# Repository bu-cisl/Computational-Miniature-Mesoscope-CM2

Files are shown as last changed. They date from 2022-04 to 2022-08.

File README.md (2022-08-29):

# Computational Miniature Mesoscope (CM<sup>2</sup>)
This is an open source repository of the Computational Miniature Mesoscope ([**CM<sup>2</sup>**](https://www.science.org/doi/full/10.1126/sciadv.abb7508)) project in the Computational Imaging Systems Lab ([**CISL**](https://sites.bu.edu/tianlab/)) at Boston University. We aim to develop next-generation “wearable” computational fluorescence microscope that achieves a centimeter-scale field-of-view (FOV) and micron-scale resolution with single-shot 3D imaging capability.
In this repository, we provide: 1) the hardware design of the CM<sup>2</sup> device including 3D printable CAD files of the LED, microlens array housing, and 3D printable freeform illuminators; 2) the Zemax models of the CM<sup>2</sup> system including the ZMX files, spectra data and coating profile; 3) the reconstruction algorithms: ADMM-based 3D deconvolution algorithm with calibrated 3D PSFs and sample measurements, and pre-trained CM<sup>2</sup>Net for fast, near-isotropic 3D reconstructions.

## Citation
If you find this project useful in your research, please consider citing our paper:

[**Yujia Xue, Ian G. Davison, David A. Boas, and Lei Tian. "Single-shot 3D wide-field fluorescence imaging with a Computational Miniature Mesoscope" Science advances 6, no. 43 (2020): eabb7508.**](https://www.science.org/doi/full/10.1126/sciadv.abb7508)

[**Yujia Xue, Qianwan Yang, Guorong Hu, Kehan Guo, and Lei Tian, "Deep-learning-augmented computational miniature mesoscope," Optica 9, 1009-1021 (2022).**](https://opg.optica.org/optica/fulltext.cfm?uri=optica-9-9-1009&id=497528)

## CM<sup>2</sup> V1
Fluorescence microscopes are indispensable to biology and neuroscience. The need for recording in freely behaving animals has further driven the development in miniaturized microscopes (miniscopes). However, conventional microscopes/miniscopes are inherently constrained by their limited space-bandwidth product, shallow depth of field (DOF), and inability to resolve three-dimensional (3D) distributed emitters. Here, we present a Computational Miniature Mesoscope (CM<sup>2</sup>) that overcomes these bottlenecks and enables single-shot 3D imaging across a 7-mm field of view and mm-scale DOF, achieving 7-μm lateral resolution and better than 200-μm axial resolution. The CM<sup>2</sup> features a compact lightweight design that integrates a microlens array for imaging and a light-emitting diode array for excitation. Its expanded imaging capability is enabled by computational imaging that augments the optics by algorithms. We experimentally validate the mesoscopic imaging capability on 3D fluorescent samples. We further quantify the effects of scattering and background fluorescence on phantom experiments.

<p align="center">
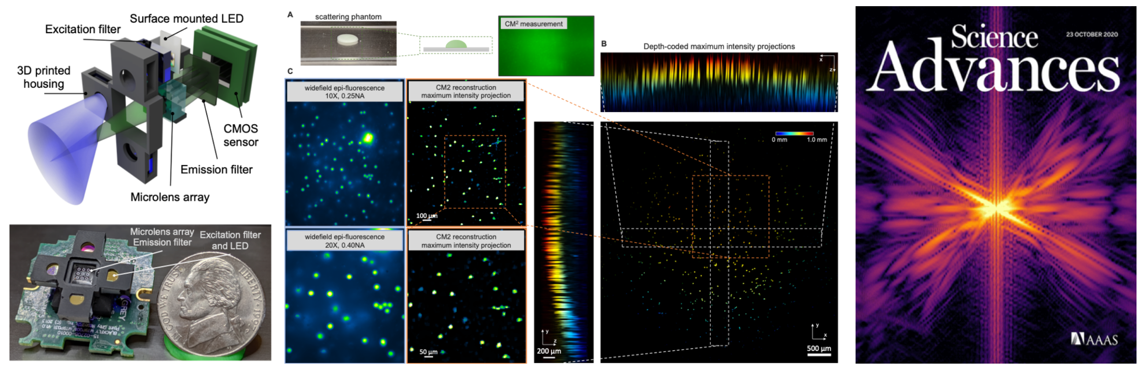
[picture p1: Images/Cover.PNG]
  
</p>

## CM<sup>2</sup> V2
Computational Miniature Mesoscope (CM<sup>2</sup>) is a recently developed computational imaging system that enables single-shot 3D imaging across a wide field-of-view (FOV) using a compact optical platform. In this work, we present CM<sup>2</sup> V2 - an advanced CM<sup>2</sup> system that integrates novel hardware improvements and a new deep learning reconstruction algorithm. The platform features a 3D-printed freeform LED collimator that achieves ~80% excitation efficiency - a ~3x improvement over our V1 design, and a hybrid emission filter design that improves the measurement contrast by >5x. The new computational pipeline includes an accurate and computationally efficient 3D linear shift-variant (LSV) forward model and a novel multi-module CM<sup>2</sup>Net deep learning model. As compared to the model-based deconvolution in our V1 system, CM<sup>2</sup>Net achieves ~8x better axial localization and ~1400x faster reconstruction speed. In addition, CM<sup>2</sup>Net consistently achieves high detection performance and superior axial localization across a wide FOV at a variety of conditions. Trained entirely on our 3D-LSV simulator generated training data set, CM<sup>2</sup>Net generalizes well to real experiments. We experimentally demonstrate that CM<sup>2</sup>Net achieves accurate 3D reconstruction of fluorescent emitters across a ~7-mm FOV and 800-μm depth, and provides ~6-μm lateral and ~25-μm axial resolution. We anticipate that this simple and low-cost computational miniature imaging system will be impactful to many large-scale 3D fluorescence imaging applications.

<p align="center">
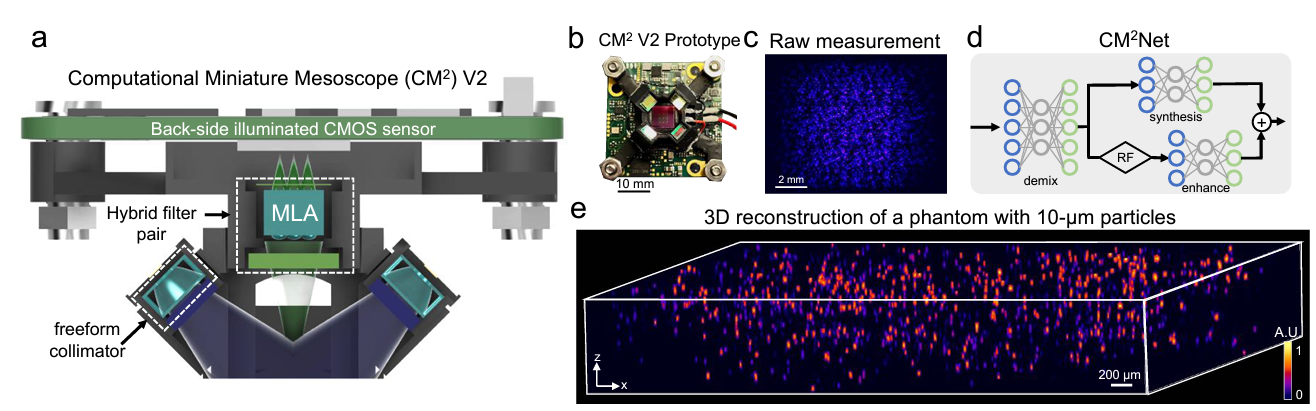
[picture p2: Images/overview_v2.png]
  
</p>

## How to use
### 1) Hardware design

The directory 'CAD_models' contains the CAD files of the CM<sup>2</sup>'s V1 and V2 systems, including the LED housing, microlens array housing, LED base plate and the freefrom collimator. All CAD models are 3D printable on lab table-top 3D printers. The subdirectory 'assembly' further provides an assembly of the CM<sup>2</sup> systems shown as below (note that the sensor is not to-scale).
<p align="center">
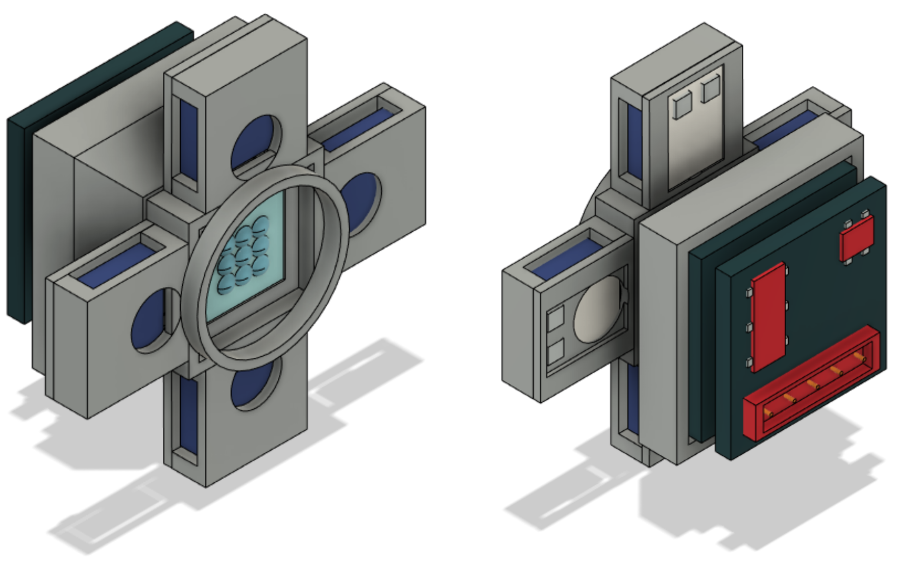
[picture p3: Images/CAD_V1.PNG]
  
</p>
<p align="center">
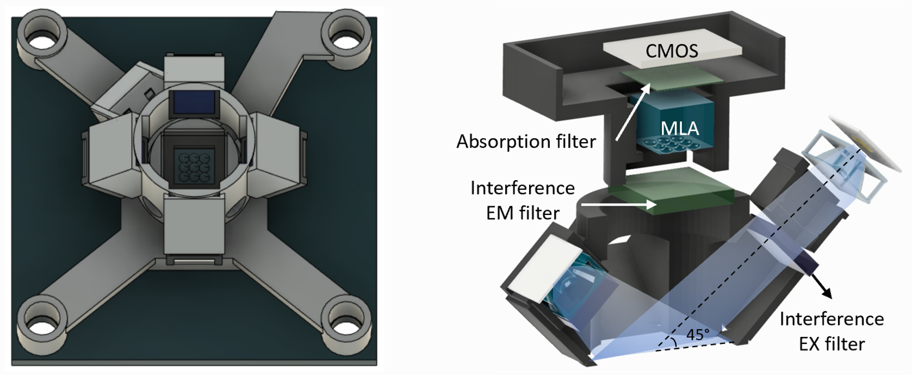
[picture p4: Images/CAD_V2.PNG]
  
</p>

The part list of all optical and electronic components used in the CM<sup>2</sup> prototypes can be found [**here**](https://docs.google.com/spreadsheets/d/1yO0x0pHvZYl-6WYT2bZiUERogTGQaifCt07Zwj_Rsxw/edit?usp=sharing).

### 2) Zemax model

To use the Zemax models, after cloning this repository, copy the coating file "cm2_coating_profiles_ver2.DAT" to the directory "Zemax\Coatings\", copy the spectra files "gfp_emission.spcd" and "led_spectrum_interp.spcd" to the directory "Zemax\Objects\Sources\Spectrum Files\", copy the CAD files (end with '.stl') to the directory "Zemax\Objects\CAD Files\", and then open "CM2_V1_opensource.zos" or "CM2_V2_opensource.zos" in Zemax to view the CM<sup>2</sup> design and ray tracing results. Pre-rendered ray tracing data can be downloaded [**here**](https://drive.google.com/drive/folders/10xuGhUDethVntPEySfjDurRVyuz1iKvr?usp=sharing).

#### CM<sup>2</sup> V1 Zemax model:
<p align="center">
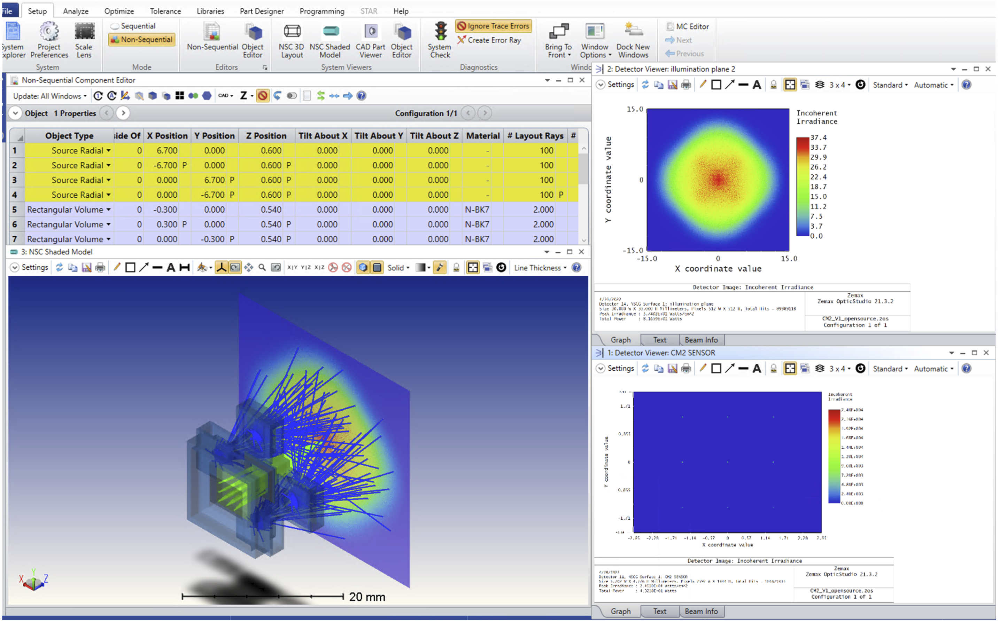
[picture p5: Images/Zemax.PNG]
  
</p>

#### CM<sup>2</sup> V2 Zemax model:
<p align="center">
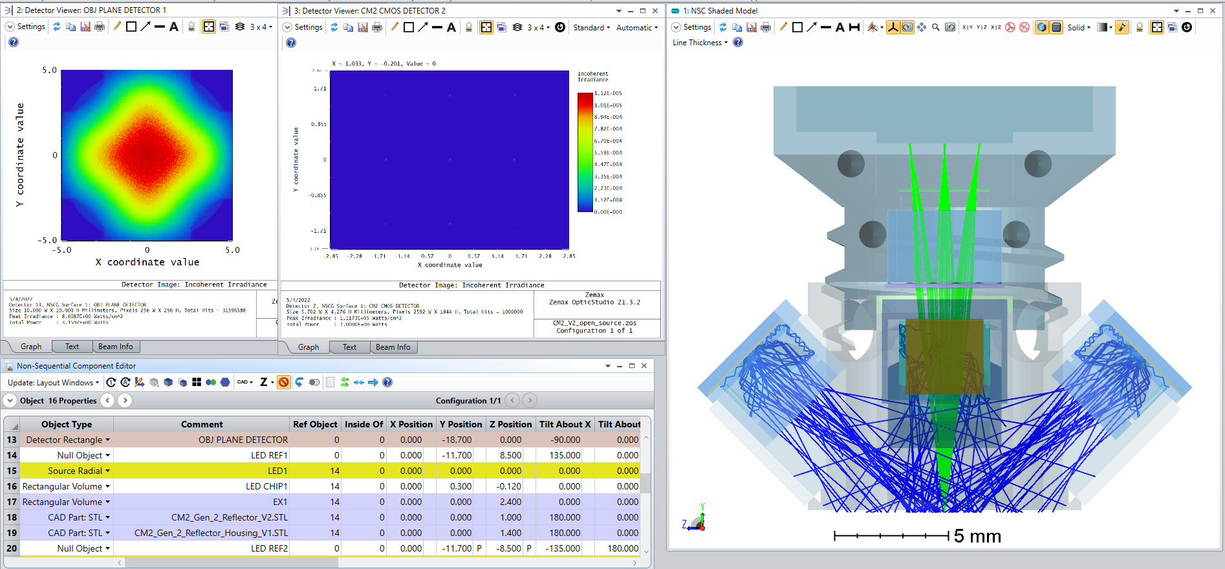
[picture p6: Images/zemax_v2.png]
  
</p>

### 3) Model-based 3D deconvolution
The script "cm2_related_code.m" in the "Algorithm" folder provides a demo of CM<sup>2</sup> 3D reconstruction pipeline on a simulated measurement using [down-sampled PSFs](https://drive.google.com/drive/folders/10xuGhUDethVntPEySfjDurRVyuz1iKvr?usp=sharing). A full-scale experimental measurement is also provided under the "Algorithm" direcory, which requires large system memory to run. The GIF file below shows the flying-through of a reconstructed 3D object (a fluorescent fiber sample) from an experimental measurement.

<p align="center">
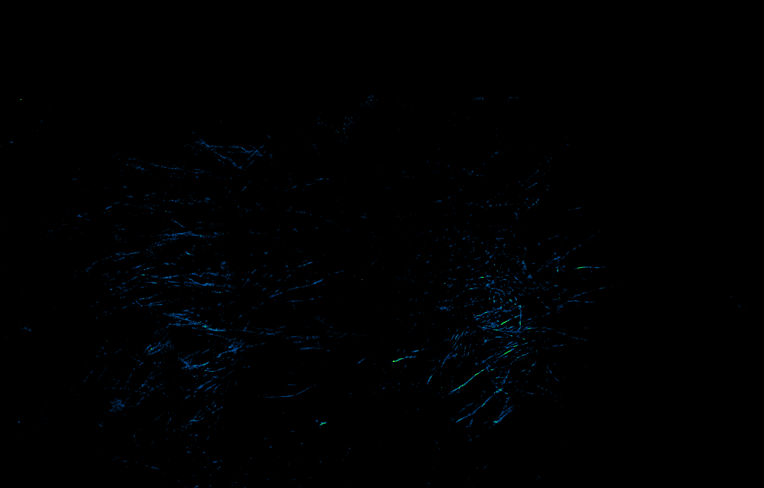
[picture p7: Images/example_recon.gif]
  
</p>

### 4）CM<sup>2</sup>Net: fast and near-isotropic 3D reconstruction
#### Install dependencies:
The CM<sup>2</sup>Net is implemented in Python 3.7 with TensorFlow 2.3.
#### Demo:
We provide an example of how to use the trained CM<sup>2</sup>net for fast and robust 3D reconstruction on CM<sup>2</sup> measurement. The script “cm2_models.py” and "pred_cm2net.py" in the "Algorithm/cm2net" folder provides the deep learning model and the inference code. The pretrained model, sample measurement and ground truth volume can be found in [cm2net data](https://drive.google.com/drive/folders/10xuGhUDethVntPEySfjDurRVyuz1iKvr?usp=sharing), which requires large system memory to run. The GIF file below shows the reconstructed 3D volume for the sample measurement.

<p align="center">
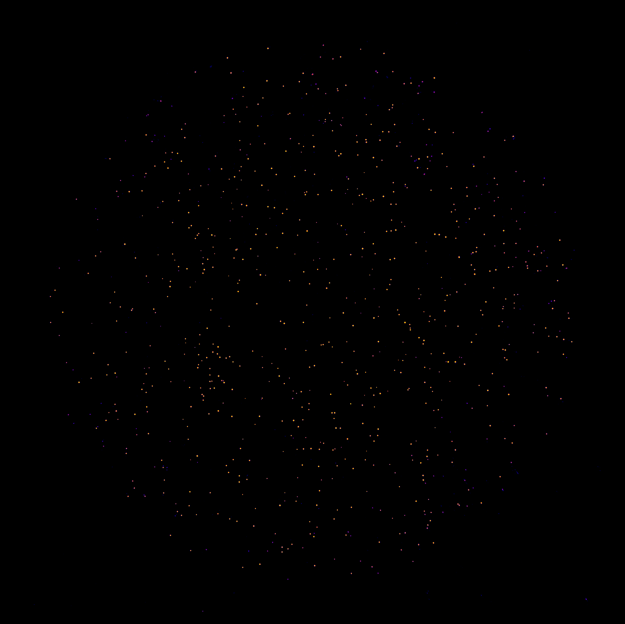
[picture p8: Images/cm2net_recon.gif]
  
</p>

## Contact
For further information, please feel free to contact us: Guorong Hu (grhu@bu.edu), Qianwan Yang (yaw@bu.edu), and Prof. Lei Tian (leitian@bu.edu).

## License
This project is licensed under the terms of the MIT license. see the [LICENSE](LICENSE) file for details

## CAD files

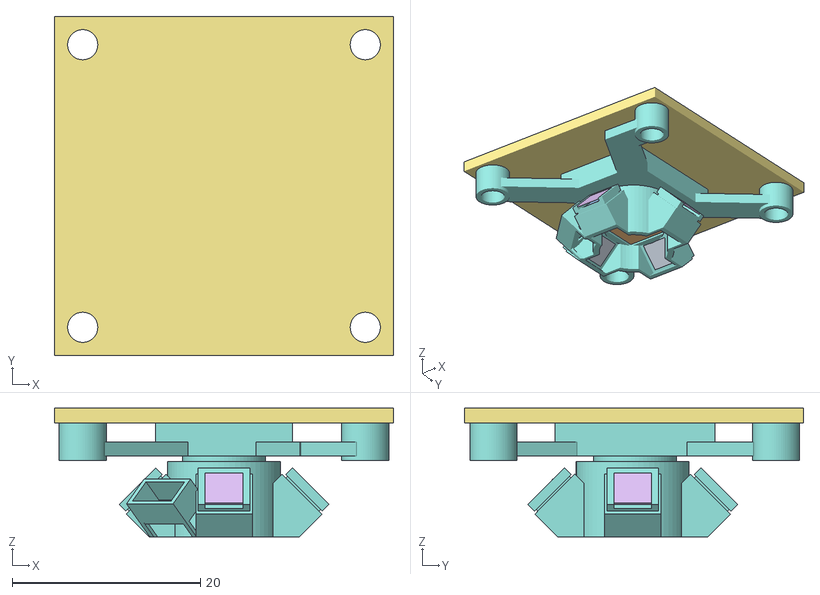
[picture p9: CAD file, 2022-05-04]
CAD_models/CM2_V2/assembly/CM2_V2_assembly_long_WD/CM2_V2_assembly_long_WD.obj
36.0 x 36.0 x 13.7

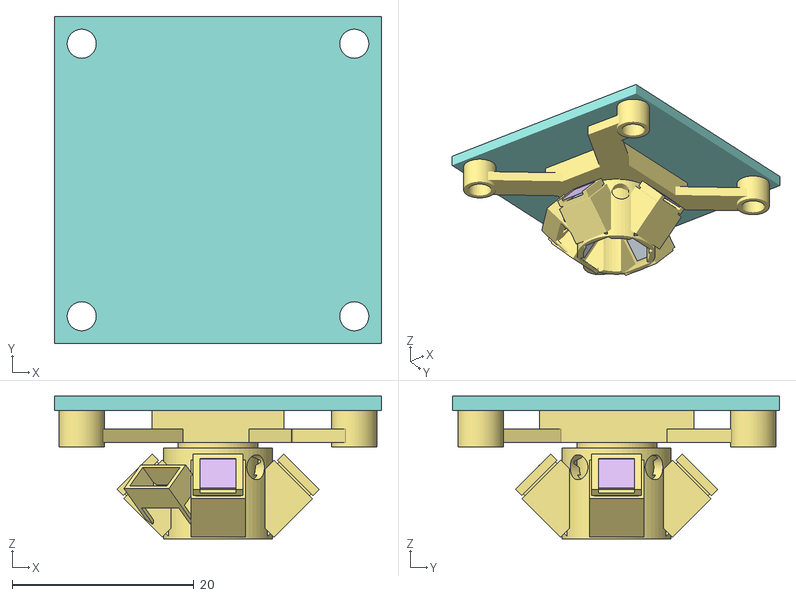
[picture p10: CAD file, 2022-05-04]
CAD_models/CM2_V2/assembly/CM2_V2_assembly_short_WD/CM2_V2_assembly_short_WD.obj
36.0 x 36.0 x 15.7

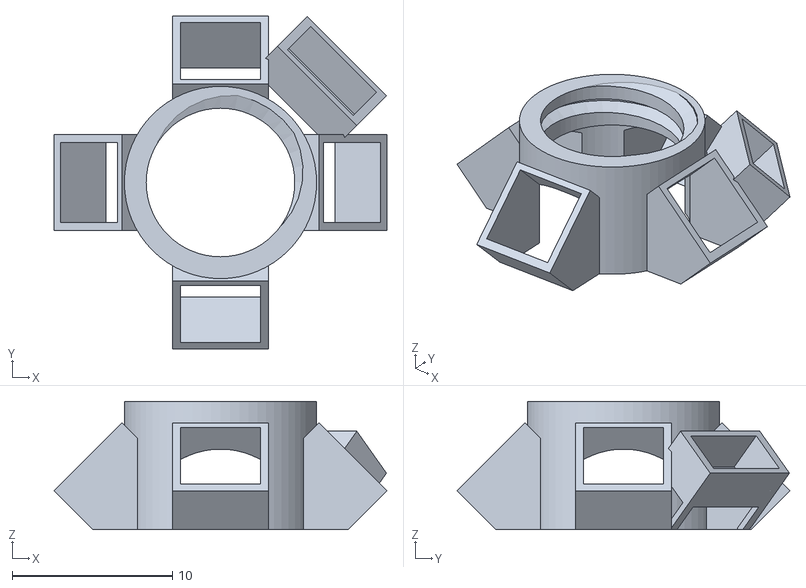
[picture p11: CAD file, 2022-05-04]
CAD_models/CM2_V2/CM2_V2_LED_array_housing_long_WD.stl
20.8 x 20.8 x 8.00

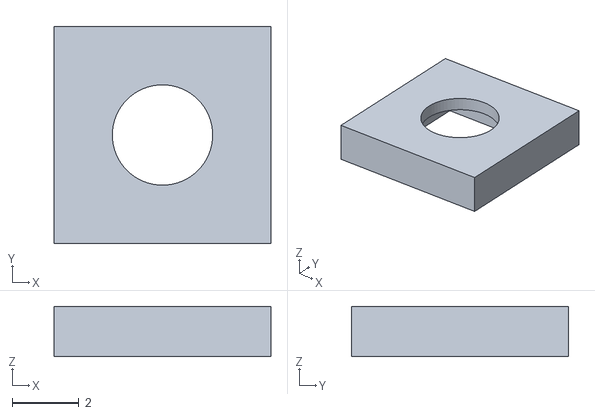
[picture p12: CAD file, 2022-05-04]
Zemax_models/CM2_V2/zemax_led_aperture.stl
6.50 x 6.50 x 1.50

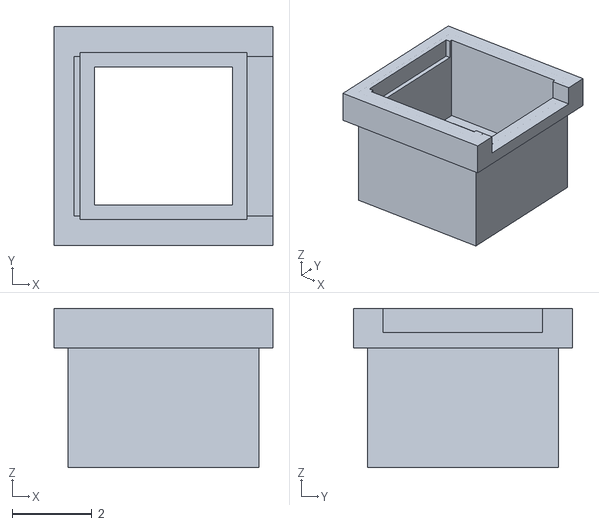
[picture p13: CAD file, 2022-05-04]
CAD_models/CM2_V2/CM2_V2_single_LED_housing.stl
5.50 x 5.50 x 4.00

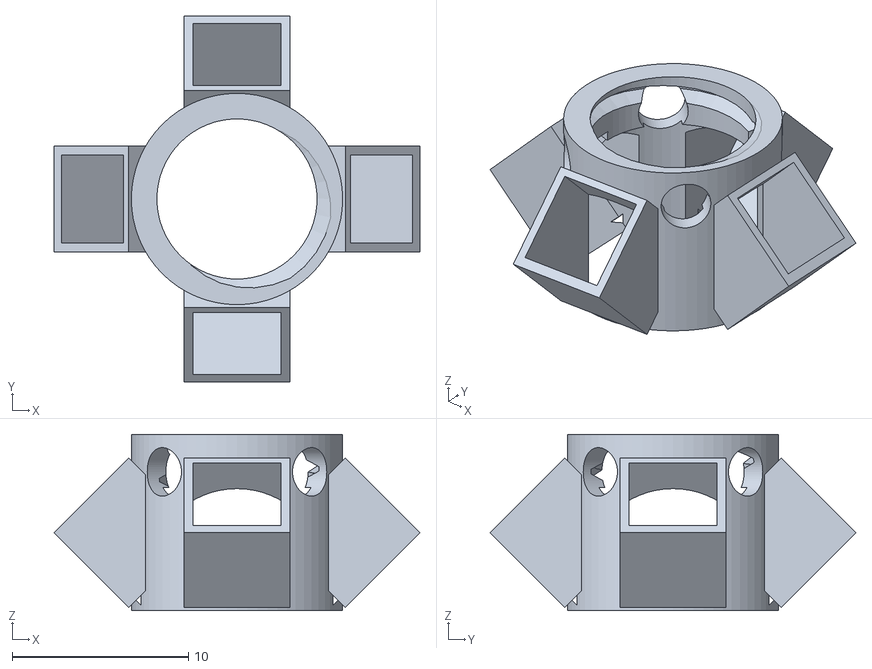
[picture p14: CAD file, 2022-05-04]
Zemax_models/CM2_V2/CM2_Gen_2_LED_Base_Threaded_V2.stl
20.8 x 20.8 x 10.0

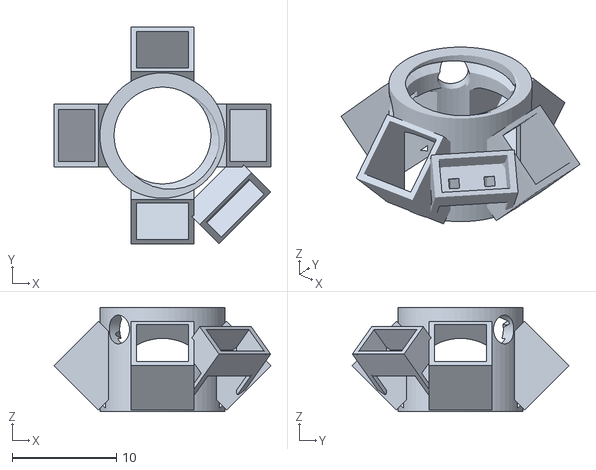
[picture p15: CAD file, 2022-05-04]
CAD_models/CM2_V2/CM2_V2_LED_array_housing_short_WD.stl.stl
20.8 x 20.8 x 10.0

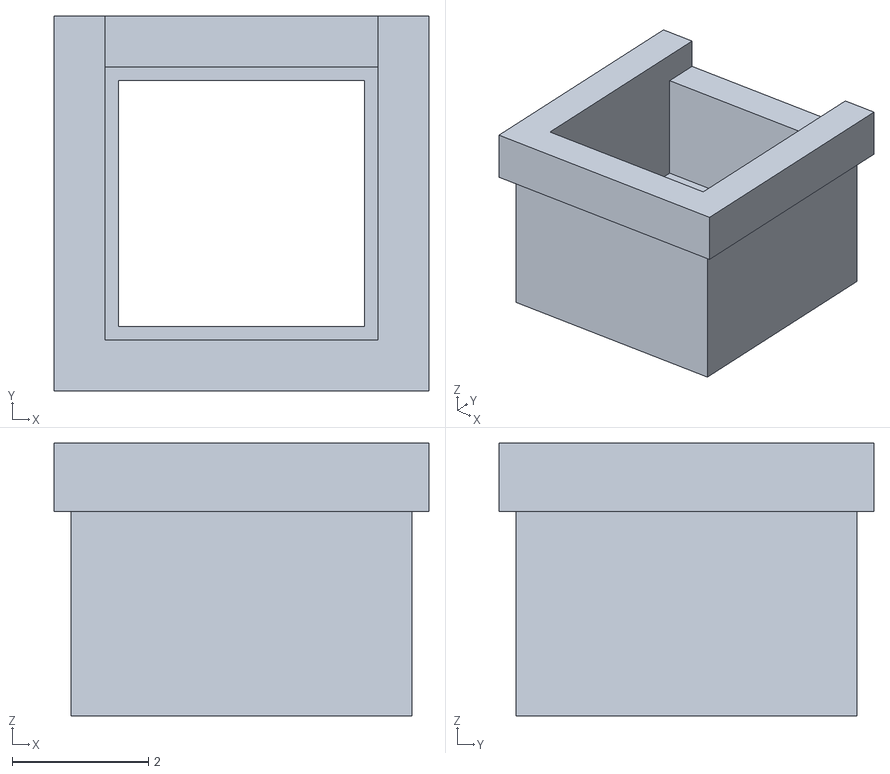
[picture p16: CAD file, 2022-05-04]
Zemax_models/CM2_V2/CM2_Gen_2_Reflector_Housing_V1.stl
5.50 x 5.50 x 4.00

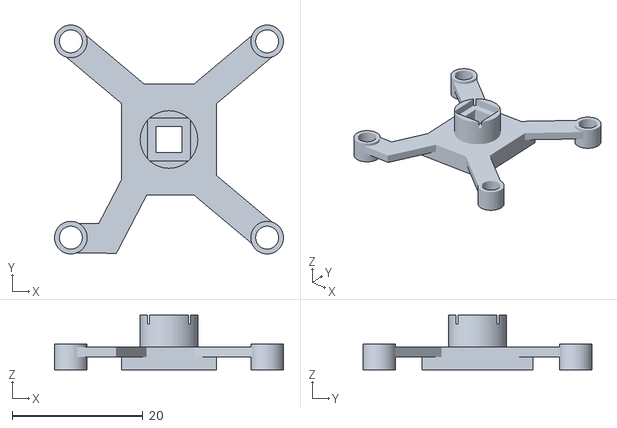
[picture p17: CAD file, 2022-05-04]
CAD_models/CM2_V2/CM2_V2_MLA_housing_IMX178.stl
35.0 x 35.0 x 8.40

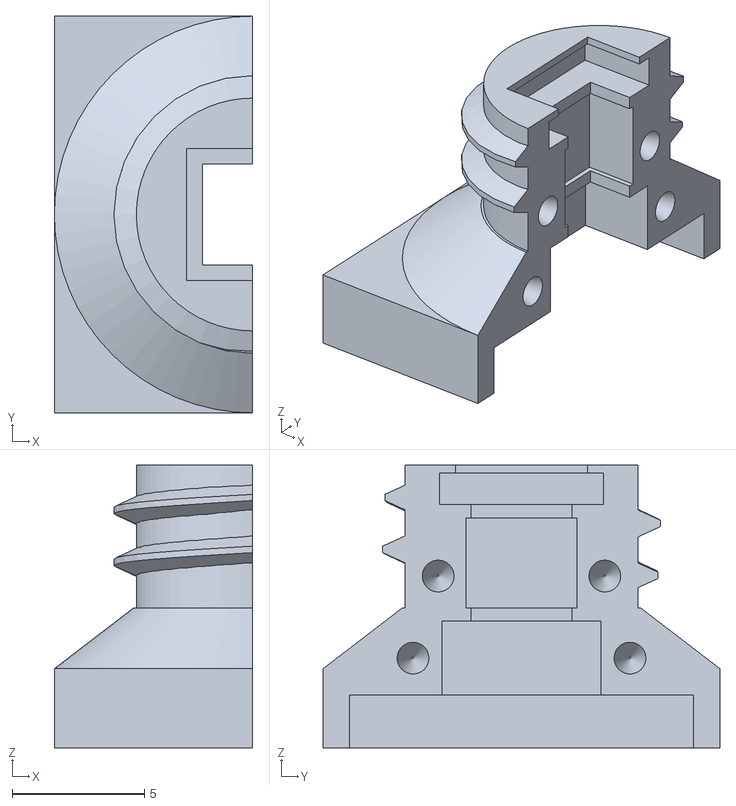
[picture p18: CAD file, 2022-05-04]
Zemax_models/CM2_V2/CM2_Gen_2_Top_Threaded_FEMALE_V2.stl
7.50 x 15.0 x 10.7

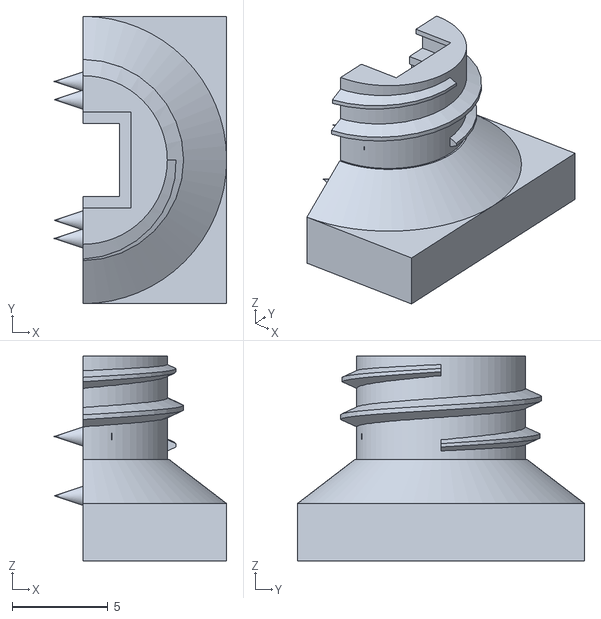
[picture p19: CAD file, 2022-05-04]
Zemax_models/CM2_V2/CM2_Gen_2_Top_Threaded_MALE_V2.stl
9.00 x 15.0 x 10.7

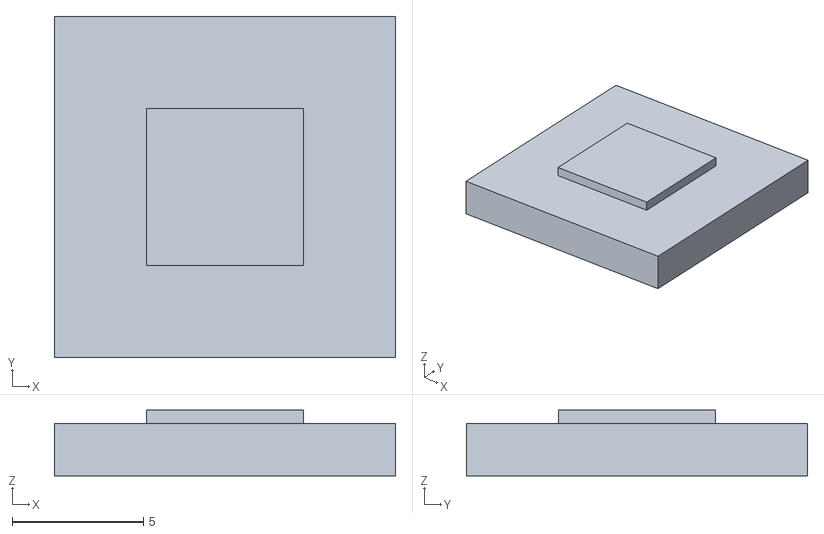
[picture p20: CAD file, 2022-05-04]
Zemax_models/CM2_V2/CM2_Gen_2_Mini_CMOS.stl
13.0 x 13.0 x 2.50

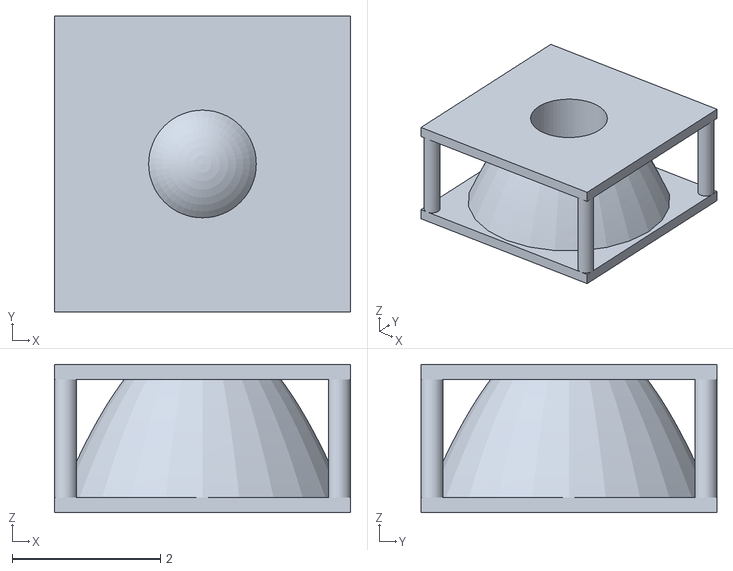
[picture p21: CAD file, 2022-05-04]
Zemax_models/CM2_V2/CM2_Gen_2_Reflector_V2.stl
4.00 x 4.00 x 2.00

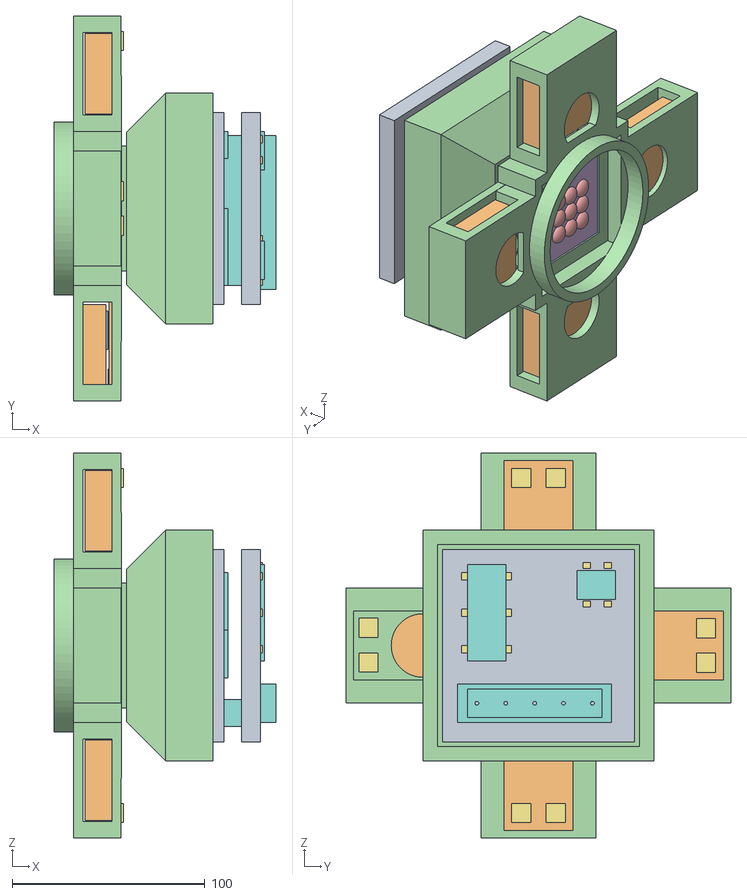
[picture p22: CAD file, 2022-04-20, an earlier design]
CAD_models/CM2_V1/assembly/assembly.obj
115.2 x 200.0 x 200.0

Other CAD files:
CAD_models/CM2_V1/mla_housing.stl
Zemax_models/CM2_V1/zemax_mla_aperture.stl
CAD_models/CM2_V1/led_housing.stl
Zemax_models/CM2_V1/mla_housing.stl
Zemax_models/CM2_V1/led_housing.stl

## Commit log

2022-04-20 update zemax models
    add zemax models of CM2 V1, spectra files, coating files, CAD files
    [CM2_V1_opensource.CFG, led_housing.stl, mla_housing.stl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]
2022-04-20 add CAD models
    [led_housing.stl, mla_housing.stl]
2022-04-20 add cm2_v1_assembly CAD
    [cm2_v1_assembly.obj]
2022-04-20 Add image folder
    [assembly.obj]
2022-05-04 re-arrange directories to separate V1 and V2 files
    [CM2_V1_opensource.CFG, assembly.obj, led_housing.stl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]
2022-05-04 add CM2 V2 CAD models
    [CM2_V2_LED_array_housing_long_WD.stl, CM2_V2_LED_array_housing_short_WD.stl.stl, CM2_V2_MLA_housing_IMX178.stl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]
2022-05-04 add CM2 V2 assembly models
    [CM2_V2_assembly_long_WD.obj, CM2_V2_assembly_short_WD.obj]
2022-05-04 add v2 zemax model
    [CM2_V2_open_source.CFG]
2022-05-04 update cad files for v2 zemax model
    [CM2_Gen_2_LED_Base_Threaded_V2.stl, CM2_Gen_2_Mini_CMOS.stl, CM2_Gen_2_Reflector_Housing_V1.stl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]
